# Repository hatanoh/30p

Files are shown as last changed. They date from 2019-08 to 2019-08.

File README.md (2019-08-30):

## はじめに
本品は試作品です。

キーボードとしての基本的な動作には問題がないことは確認していますが、多少ネジ穴位置や組み立て難易度に難があります。

その辺りご了承ください。

## どんなキーボード
BLE Micro Proを使用する31～35キーで3段の細長いキーボードで単3電池1本で駆動します。

トッププレート裏にBMPを配置しているのでProMicroを重ねないタイプの普通のキーボードぐらいの厚さ(7mmスペーサー使用)になっています
(Bootleg31除く/Bootleg31は11mm)

### Bootleg31
Nomu30の配列でBMP対応して、レバースイッチを付けたキーボード。
レバースイッチは親指で操作してレイヤ切り替えなどに使うことを想定しています。

### Soroban30(Bootleg30)
40%キーボードの最下段をちょん切って、「,」「.」のスペースの2uスペースを置いたキーボード

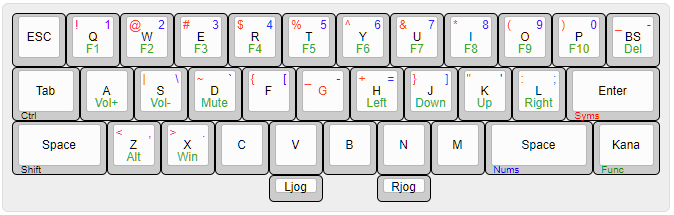
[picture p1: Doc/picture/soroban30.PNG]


スペースを小指で叩くちょっと苦しいキーボード

### Ally13(黒)
soroban30を13°づつ折り曲げて隙間にスイッチを一つ入れたもの

Ally24の中央のBSがない配列になります

### Ally24(赤)
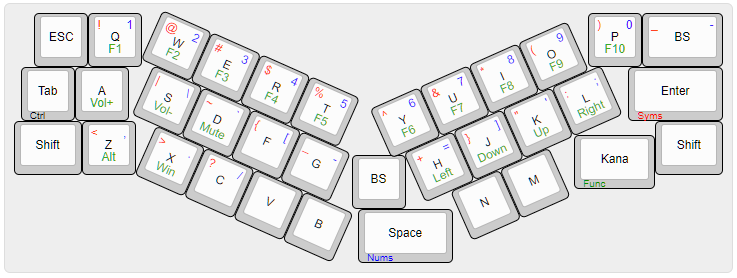
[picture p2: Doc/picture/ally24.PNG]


soroban30を24°づつ折り曲げて隙間にスイッチを二つ入れたもの

キー配置の詳細はソースのkeymap.cを参照してください

## ビルドガイド
[Build Guide](https://github.com/hatanoh/30p/blob/master/Doc/buildguide.md)

## ファームウェア
[Firmware/BLE Micro Pro](https://github.com/hatanoh/qmk_firmware)

[キーボード固有部分](https://github.com/hatanoh/qmk_firmware/tree/nrf52/keyboards/sarasarado30_ble)

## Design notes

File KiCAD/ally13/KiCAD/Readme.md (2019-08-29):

フットプリントは以下の物と、KiCAD標準の物を使用しています。

based on kicad library
BatteryHolder_Keystone_2466_1xAAA_reversible.kicad_mod
C_1608SMD_reversible.kicad_mod
R_1608SMD_reversible.kicad_mod
Diode_SOD-323_Reversible.kicad_mod
M-05720.kicad_mod

from lily58
HOLE_M2.kicad_mod
HOLE_M2_TH.kicad_mod

based on lily58
Diode_SOD123_Reversible.kicad_mod
TRRS_JACK_MJ4PP9.kicad_mod
TACT_SWITCH_TVBP06.kicad_mod

based on following page
https://geekhack.org/index.php?topic=94663.msg2578173#msg2578173
https://www.dropbox.com/s/f2kuubuw87bpgwl/CPG151101S11.zip?dl=0

CPG151101S11_frame.kicad_mod
CPG151101S11_frame_H.kicad_mod
CPG151101S11_reversible3.kicad_mod
CPG151101S11_reversible3_1.50_h.kicad_mod

made by me
BLEMicroPro.kicad_mod
SLIDE_SWITCH_ESD175202.kicad_mod
SLIDE_SWITCH_SK-12D01.kicad_mod
PKLCS1212E4001-HOLE.kicad_mod
PKLCS1212E4001.kicad_mod

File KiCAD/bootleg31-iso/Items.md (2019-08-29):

## 内容物

### 本体
PCB				2枚
PCBトッププレート		2枚
PCBボトムプレート		2枚
PCB回路カバー			2枚
SMDダイオード			64個
TRRSジャック			2個
タクトスイッチ			2個
ゴム足				8個

### 電源回路キット
スライドスイッチ		2個
AAA電池ケース			2個
TPS61221			2個
LQH3NPZ4R7MMEL			2個
1806 10uF			4個

### MXキット
MXソケット			64個
M2キャップボルト(4mm)		36個
M2-7mmスペーサー		18個

### LPキット
chocソケット			64個
M2キャップボルト(4mm)		18個
M2キャップボルト(3mm)		18個
M2-7mmスペーサー		4個
M2-4mmスペーサー		14個

### その他購入すべき材料
BLEMicroPro または ProMicro	2個
コンスルー12pin	   		4本
MXまたはkailhChocスイッチ	64個
　こちらではkailh Choc, Aliaz silent, ZilentV2, Cream Switchを確認しています、Chream Switchの場合ややきつめにはまります。

お好きなキーキャップ		62個(1u)
				2個(1.5u)
microUSBケーブル		1本
TRSまたはTRRS(推奨)ケーブル	1本(無線で使用するなら不要)

### 必要に応じて購入すべき材料
秋月()
昇圧型DCDCコンバータ StepUp/DIP 3.3Vタイプ Ver2(M-05720)
http://akizukidenshi.com/catalog/g/gM-05720/
		     		2個
8pin丸ピンソケット		2個
M2スペーサ(11mmまたは15mm)	4個

## 必要な工具
半田ごて
小手台
ピンセット
ニッパ
1.5mm六角レンチ
テスター
ヘッドルーペ(あれば)
耐熱マット(あれば)
SMDクランプあるいはそれのような物(あれば)

半田(0.8mm)
フラックス
ネジ止め剤(あれば)
マスキングテープ

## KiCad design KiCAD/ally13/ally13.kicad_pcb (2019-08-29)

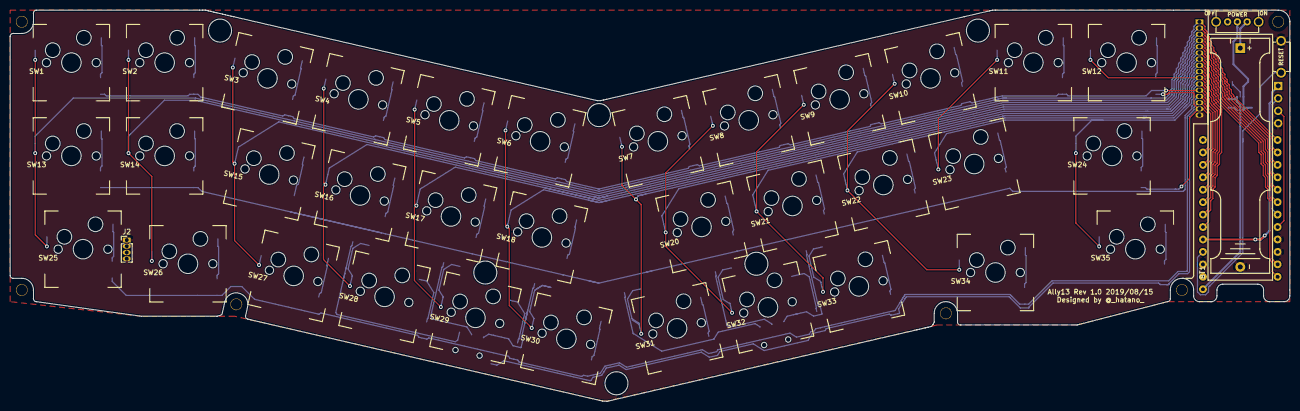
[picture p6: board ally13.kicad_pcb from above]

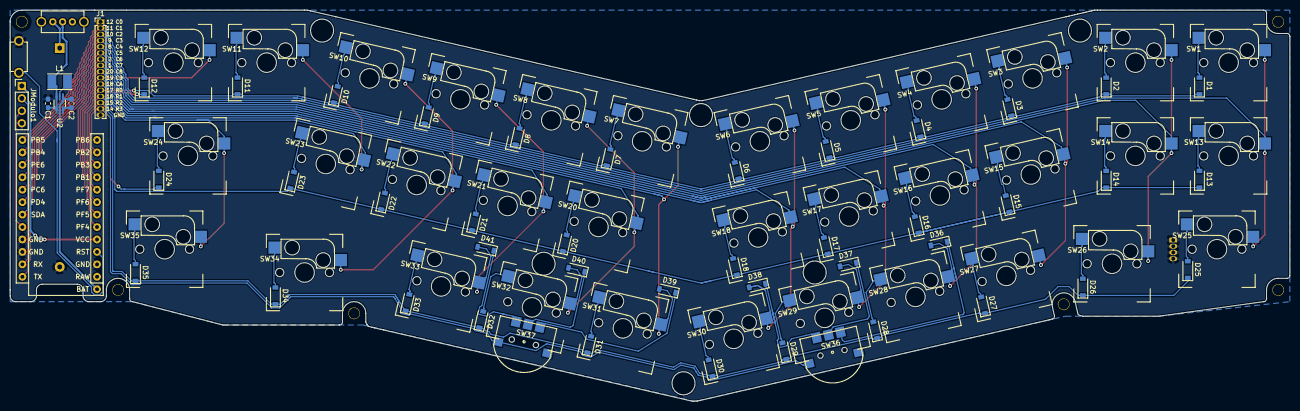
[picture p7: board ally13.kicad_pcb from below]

Board: 2 copper layers, 261.3 x 79.9 mm, 99 parts (50 on the bottom side), 64 nets.

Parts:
BT1: Battery_Cell; BatteryHolder_Keystone_2466_1xAAA
C1, C2: 10uF; C_0603_1608Metric_Pad1.05x0.95mm_HandSolder
D1, D2, D3, D4, D5, D6, D7, D8, D9, D10, D11, D12, D13, D14, D15, D16, D17, D18, D20, D21, D22, D23, D24, D25, D26, D27, D28, D29, D30, D31, D32, D33, D34, D35, D36, D37, D38, D39, D40, D41: D; D_SOD-123
H1, H2, H4, H5, H6, H10: MountingHole; HOLE_M2_TH
H3, H7, H8, H9, H11, H12: MountingHole; HOLE_M2
J1: Conn_01x16; PinHeader_1x16_P1.27mm_Conthrough
J2: Conn_01x04; PinHeader_1x04_P1.27mm_Conthrough
JModulo1: Conn_01x04; PinHeader_1x04_P2.54mm_Vertical
L1: 4.7uH; L_Taiyo-Yuden_NR-30xx_HandSoldering
SW1, SW2, SW3, SW4, SW5, SW6, SW7, SW8, SW9, SW10, SW11, SW12, SW13, SW14, SW15, SW16, SW17, SW18, SW20, SW21, SW22, SW23, SW26, SW27, SW28, SW29, SW30, SW31, SW32, SW33: SW_Push; CPG1511_1u
SW24, SW34: SW_Push; CPG1511_1.75u
SW25, SW35: SW_Push; CPG1511_1.25u
SW36, SW37: TMHU27; THMU27
SW38: SW_RST; TACT_SWITCH_TVBP06
SW39: SW_PWR; SLIDE_SWITCH_SK-12D01
U1: BLE-Micro-Pro-2; BLEMicroPro-2N
U2: TPS61221; SOT-363_SC-70-6_Handsoldering

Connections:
BAT: C2.1, U1.25, U2.2, U2.4
C0: J1.1, SW1.1, SW13.1, SW25.1, U1.12
C1: J1.2, SW2.1, SW14.1, SW26.1, U1.11
C2: J1.3, SW3.1, SW15.1, SW27.1, U1.10
C3: D36.2, J1.4, SW4.1, SW16.1, SW28.1, U1.9
C4: D37.2, J1.5, SW5.1, SW17.1, SW29.1, U1.8
C5: D38.2, J1.6, SW6.1, SW18.1, SW30.1, U1.7
C6: D39.2, J1.7, SW7.1, SW31.1, U1.2
C7: D40.2, J1.8, SW8.1, SW20.1, SW32.1, U1.1
C8: D41.2, J1.9, SW9.1, SW21.1, SW33.1, U1.20
C9: J1.10, SW10.1, SW12.1, SW22.1, SW34.1, U1.19
C10: J1.11, SW11.1, SW23.1, SW24.1, SW35.1, U1.18
GND: BT1.2, C1.2, C2.2, J1.16, J2.1, J2.2, J2.3, J2.4, JModulo1.4, SW38.2, U1.3, U1.4, U1.23, U2.3
unnamed: BT1.1, SW39.2
unnamed: D1.2, SW1.2
unnamed: D2.2, SW2.2
unnamed: D3.2, SW3.2
unnamed: D4.2, SW4.2
unnamed: D5.2, SW5.2
unnamed: D6.2, SW6.2
unnamed: D7.2, SW7.2
unnamed: D8.2, SW8.2
unnamed: D9.2, SW9.2
unnamed: D10.2, SW10.2
unnamed: D11.2, SW11.2
unnamed: D12.2, SW12.2
unnamed: D13.2, SW13.2
unnamed: D14.2, SW14.2
unnamed: D15.2, SW15.2
unnamed: D16.2, SW16.2
unnamed: D17.2, SW17.2
unnamed: D18.2, SW18.2
unnamed: D20.2, SW20.2
unnamed: D21.2, SW21.2
unnamed: D22.2, SW22.2
unnamed: D23.2, SW23.2
unnamed: D24.2, SW24.2
unnamed: D25.2, SW25.2
unnamed: D26.2, SW26.2
unnamed: D27.2, SW27.2
unnamed: D28.2, SW28.2
unnamed: D29.2, SW29.2
unnamed: D30.2, SW30.2
unnamed: D31.2, SW31.2
unnamed: D32.2, SW32.2
unnamed: D33.2, SW33.2
unnamed: D34.2, SW34.2
unnamed: D35.2, SW35.2
unnamed: D36.1, SW36.1
unnamed: D37.1, SW36.T
unnamed: D38.1, SW36.2
unnamed: D39.1, SW37.1
unnamed: D40.1, SW37.T
unnamed: D41.1, SW37.2
unnamed: L1.1, U2.5
R0: D1.1, D2.1, D3.1, D4.1, D5.1, D6.1, D7.1, D8.1, D9.1, D10.1, D11.1, J1.12, U1.17
R1: D13.1, D14.1, D15.1, D16.1, D17.1, D18.1, D20.1, D21.1, D22.1, D23.1, J1.13, U1.16
R2: D25.1, D26.1, D27.1, D28.1, D29.1, D30.1, D31.1, D32.1, D33.1, D34.1, D35.1, J1.14, U1.15
R3: D12.1, D24.1, J1.15, SW36.C, SW37.C, U1.14
RST: SW38.1, U1.22
SCL: JModulo1.3, U1.5
SDA: JModulo1.2, U1.6
VCC: JModulo1.1, U1.21
cell: C1.1, L1.2, SW39.1, U2.1, U2.6

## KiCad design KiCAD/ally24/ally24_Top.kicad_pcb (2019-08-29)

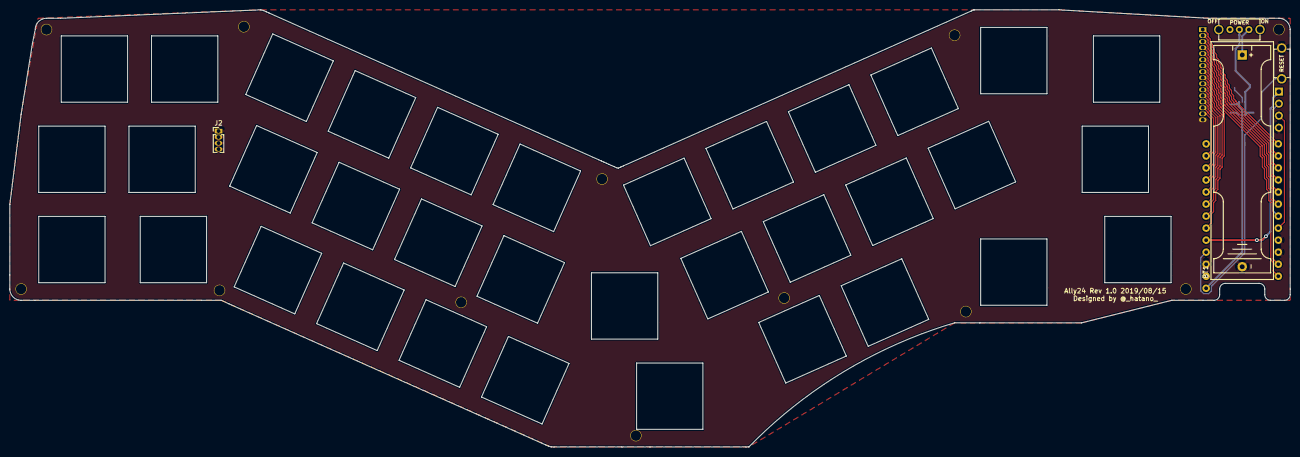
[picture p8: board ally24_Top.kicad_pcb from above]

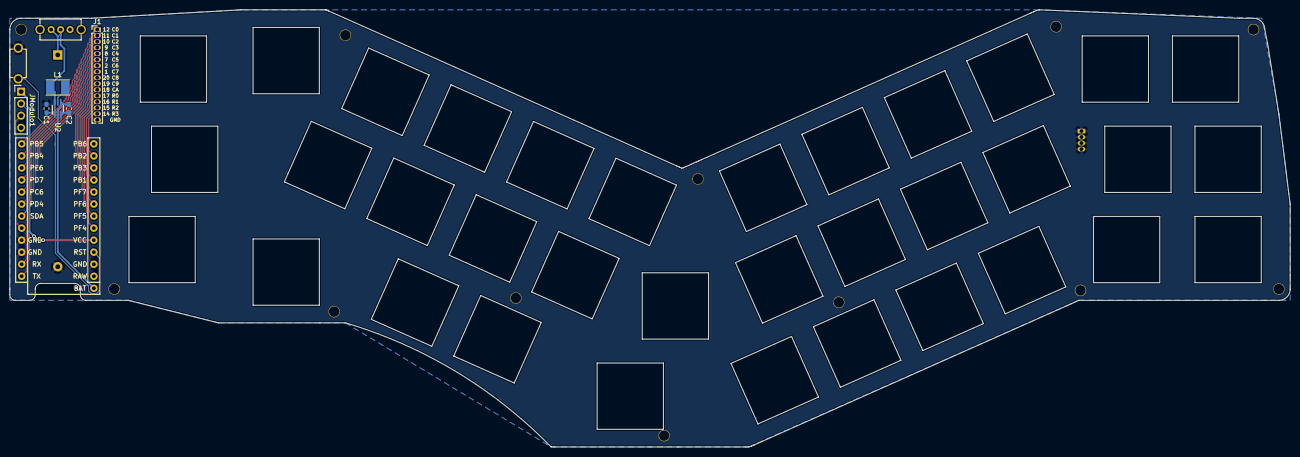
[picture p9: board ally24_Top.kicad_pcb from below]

Board: 2 copper layers, 270.3 x 92.3 mm, 58 parts (8 on the bottom side), 24 nets.

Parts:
BT1: Battery_Cell; BatteryHolder_Keystone_2466_1xAAA
C1, C2: 10uF; C_0603_1608Metric_Pad1.05x0.95mm_HandSolder
H1, H2, H3, H4, H5, H6, H7, H8, H9, H10, H11, H12: MountingHole; HOLE_M2
J1: Conn_01x16; PinHeader_1x16_P1.27mm_Conthrough
J2: Conn_01x04; PinHeader_1x04_P1.27mm_Conthrough
JModulo1: Conn_01x04; PinHeader_1x04_P2.54mm_Vertical
L1: 4.7uH; L_Taiyo-Yuden_NR-30xx_HandSoldering
SW1, SW2, SW3, SW4, SW5, SW6, SW7, SW8, SW9, SW10, SW11, SW12, SW13, SW14, SW15, SW16, SW17, SW18, SW19, SW20, SW21, SW22, SW23, SW24, SW25, SW26, SW27, SW28, SW29, SW30, SW31, SW32, SW33, SW34, SW35: SW_Push; CPG1511_1350_hole
SW38: SW_RST; TACT_SWITCH_TVBP06
SW39: SW_PWR; SLIDE_SWITCH_SK-12D01
U1: BLE-Micro-Pro-2; BLEMicroPro-2N
U2: TPS61221; SOT-363_SC-70-6_Handsoldering

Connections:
BAT: C2.1, U1.25, U2.2, U2.4
C0: J1.1, U1.12
C1: J1.2, U1.11
C2: J1.3, U1.10
C3: J1.4, U1.9
C4: J1.5, U1.8
C5: J1.6, U1.7
C6: J1.7, U1.2
C7: J1.8, U1.1
C8: J1.9, U1.20
C9: J1.10, U1.19
C10: J1.11, U1.18
GND: BT1.2, C1.2, C2.2, J1.16, J2.1, J2.2, J2.3, J2.4, JModulo1.4, SW38.2, U1.3, U1.4, U1.23, U2.3
unnamed: BT1.1, SW39.2
unnamed: L1.1, U2.5
R0: J1.12, U1.17
R1: J1.13, U1.16
R2: J1.14, U1.15
R3: J1.15, U1.14
RST: SW38.1, U1.22
SCL: JModulo1.3, U1.5
SDA: JModulo1.2, U1.6
VCC: JModulo1.1, U1.21
cell: C1.1, L1.2, SW39.1, U2.1, U2.6

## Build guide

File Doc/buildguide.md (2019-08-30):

# ビルドガイド

## 略語
以下のようにキーボード名を省略します

|名称|略称|
|---|----|
|Bootleg31 |BL31|
|Soroban30(Bootleg30)|BL30|
|Ally13 |AL13|
|Ally24 |AL24|

## 必要な部品
今回は基板とトップ/ボトムプレートのみの提供であるため
以下のものが必要です。

さらに単4乾電池1本が必要です。ニッケル水素充電池でも問題ありません(0.7Vまでシャットダウンしないので過放電には気を付けてください)。

|品名|BL31|BL30|AL13|AL24|
|----|----|----|----|----|
|BLE microPro(Boothのぎけす屋,遊舎工房) | 1| 1| 1| 1|
|コンスルー(2.54mm/12pin,遊舎工房) | 2| 2| 2| 2|
|M2 4mm  超低頭ネジ(日東精工 ラミクス, Wilcoなど)|22|22|24|24|
|M2 両メススペーサ 7mm(8.5mm) | 0|11|12|12|
|M2 両メススペーサ 11mm |11| 0| 0| 0|
|ゴム足 8mm | 6| 6| 6| 6|
|電源部品(別表参照) |一式|一式|一式|一式|
|コンスルー(別表参照) |不要|一式|一式|一式|
|スライドスイッチ横型(SK-12D01-VG4, 秋月P-08789) | 1| 1| 1| 1|
|タクトスイッチ(TVBP06, 秋月P-08073, 遊舎工房) | 1| 1| 1| 1|
|単4電池ケース(ピン型, 秋月P-02670) | 1| 1| 1| 1|
|レバースイッチ(TMHU26/27,秋月P-08070,P-08071) | 2| 2| 2| 2|
|SMDダイオード(1N4148W,秋月I-07084,遊舎工房) |37|39|40|41|
|2u PCB取り付けスタビライザ(遊舎工房など) | 1| 1| 0| 0|
|kailhMXソケット(遊舎工房など) |31|33|34|35|
|MXスイッチ(各種ショップ) |31|33|34|35|
|キーキャップ 1u |28|28|30|29|
|キーキャップ 1.25u | 0| 2| 2| 2|
|キーキャップ 1.5u | 1| 0| 0| 2|
|キーキャップ 1.75u | 1| 1| 2| 2|
|キーキャップ 2u | 0| 1| 0| 0|
|キーキャップ ISOEnter | 1| 0| 0| 0|

BL30及びAL24はキースイッチとネジ頭が重なる箇所があります(各1箇所/購入時に確認して下さい)ので、少なくともそこ箇所はラミクスを使用する必要があります。

レバースイッチはオプションです。必ずしも必要はないでしょう(BL31以外では未検証です)

レバースイッチを実装しない場合はダイオードは-6個してください。

BL31以外でレバースイッチを実装する場合は7mmのスペーサを8.5mmに変更する必要があります(未検証)8mmでも良いかもしれません。

レバースイッチはTMHU26あるいは27の好きな方を使ってください。TMHU28は接点数が異なるため使用できません。

電源部品だけは入手が面倒なのでセットを別に用意しています。コンデンサも付けてありますが小さいのでなくした場合には秋月などで0603 10uFの積層セラミックコンデンサを購入してください。

|品名|数量|
|----|----|
|DCDCコンバータ(TI TPS61221DCK) |1|
|インダクタ 4.7uH 3030(Murata LQH3NPZ4R7MMEL) |1|
|コンデンサ 10uF 0603(Murata GRM188R60J106KE47D) |2|

トッププレートとキーボード基板を結ぶコンスルーも入手に難があるので別に用意しています

|品名|数量|
|----|----|
|コンスルー(1.27mm 16pin H3.5mm) |1|

キースイッチやキーキャップはお好みのものを使用してください。
XDAやDSAのような段による形状の違いがないキーキャップの方が合わせやすいかもしれません。
特にSoroban30(Bootleg30)は40%キーボード向けのキーキャップセットを使うと良いかもしれません。

## トッププレート
BMPと電源回路とリセットスイッチはトッププレートに載っています。
1. 裏面にTPS61221とインダクタ(4.7uH)とコンデンサ(10uF)2個を実装します。
2. 裏側から、スライドスイッチ、リセットスイッチを実装します。
3. 表から、電池ケースを実装します。
4. 電池を入れ、スイッチをONにし、BATとGNDの間が3.3Vであることを確認する。
(cscsシリーズと異なり秋月DCDC昇圧基板を使用するようなワークアラウンドはありません)

テスタで電源が期待通りの電圧を出力をしてることを確認するまでは*絶対にBLE Micro Proを接続してはいけません*。

電源部分の組み立ては[cscsシリーズのビルドガイド](https://github.com/hatanoh/cscs_family/blob/master/Doc/buildguide.md)も参考になると思います。

## キーボード基板
1. ダイオードを半田付けします。レバースイッチを実装しない場合は横向きのダイオードは半田付けする必要はありません。が、不安だったら全部付けても大丈夫です。
向きはシルクの通りで縦横それぞれですべて同じです。
2. ソケットを半田付けします。
3. 必要に応じて、レバースイッチを半田付けしてください。浮かないように気をつけて取り付けてください。

## 基板の組み立て
1. トッププレートにスペーサーをネジ止めしていきます。ものによってはネジ頭がキースイッチホールにはみ出たりするかもしれませんし、キースイッチに重なったりします。
その場合削ったり取り付けを諦めたりしてください。ラミクスを使っていれば、多少キースイッチにかぶっていても問題はないんじゃないかと思います。
2. トッププレートにスイッチをはめ込みます。スイッチによってはきついことがありますので、削ったり諦めたりしてください(今回のBL30の穴はやや小さめでした)
3. スイッチの端子が曲がっていないことを注意深く確認してください。曲がっていたらまっすぐに直して下さい。
4. トッププレートの電源回路側、の1\.27mmスルーホールに1\.27mmコンスルーを差し込み、キースイッチをソケットにさすのと一緒にキーボード基板にそっと押し込んでいきます。
5. BMPをコンスルーでトッププレート裏に取り付けます。
6. ボトムプレートを取り付け、ネジ止めしていきます。こちらはねじ頭がゴム足より低ければ必ずしもラミクスを使う必要がありません。
7. ゴム足を貼ります。貼る場所が丸く指定されていますのでそこに貼ると良いでしょう(BL31以外)

## ファームウェア
ビルド環境の整備は[BLE Micro Pro](https://github.com/sekigon-gonnoc/BLE-Micro-Pro) のページを参照してください。
他関連情報は[サリチル酸さんのガイド](https://salicylic-acid3.hatenablog.com/entry/BMP-Introduction)やそこからたどるページを参照されると良いかと思います。

1. ソースを取得します
```
% git clone -b nrf52 https://github.com/hatanoh/qmk_firmware.git 
```
2. ビルドします

BL31
```
% make sarasarado30_ble/b31ij:default:nrfutil
```
BL30
```
% make sarasarado30_ble/b30aj:default:nrfutil
```
AL13
```
% make sarasarado30_ble/ally13:default:nrfutil
```
AL24
```
% make sarasarado30_ble/ally24:default:nrfutil
```
3. ビルドが終わって接続待ちのテケテケが出始めたら、リセットボタンを押しながらusbケーブルを繋ぐ

## 動作確認
1. BMPにファームを書き込みます。
2. キーの動作を確認します。動かないキーがあった場合、キースイッチの端子が折れていたり、ダイオードの半田付けが甘かったり、極性が反対だったりしないか確認します。
